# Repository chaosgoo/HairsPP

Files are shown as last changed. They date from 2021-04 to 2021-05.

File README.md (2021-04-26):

# HairsPP

语言: 中文, [English](README.En.md)




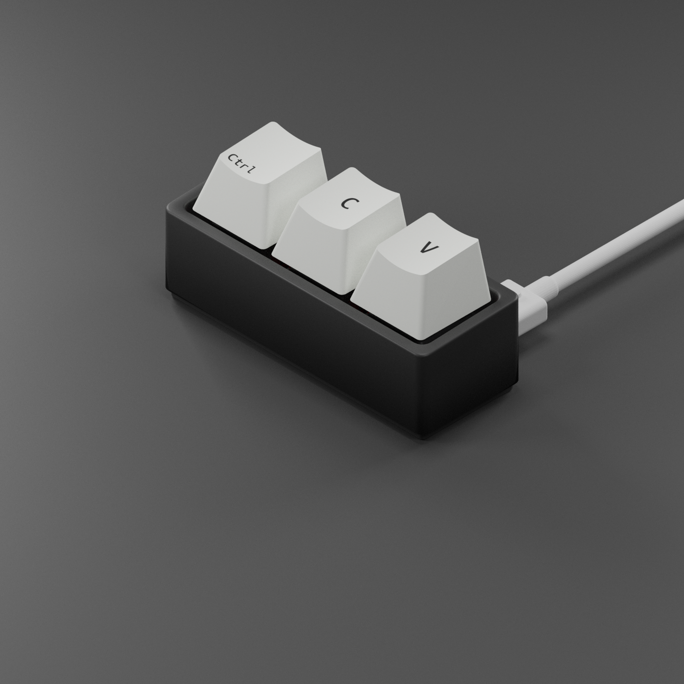
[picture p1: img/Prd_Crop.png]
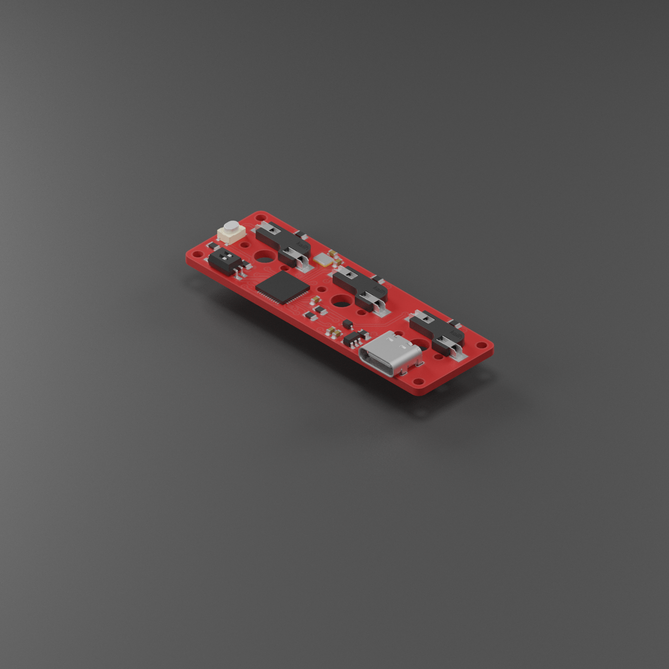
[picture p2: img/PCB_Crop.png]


[HairsPP](https://github.com/chaosgoo/HairsPP) 是Hairs Plus Plus的简写。[HairsPP](https://github.com/chaosgoo/HairsPP)是一个三键的机械键盘。
* 支持热插拔
* 支持连发模式
* 易学的源码
* 自定义按键映射

## TODO
* ~~20210412:电路~~ 
* ~~20210418:初版源码~~ 
* 壳体 
* PC端配置软件

## 食用指南
开关状态(左5号右6号) | 模式名称 | 描述 
:-:|:-:|:-:
00 | 配置模式 | 串口发送三个字符会自动分配到三个键上，一切正常串口会收到"ok"字符。
10 | 连发模式 | 按住按钮会不断触发点击事件
01 | 复位模式 | 恢复默认键位，通电前配置才有效
11 | 常规模式 | 普通键盘的普通行为

## 材料清单

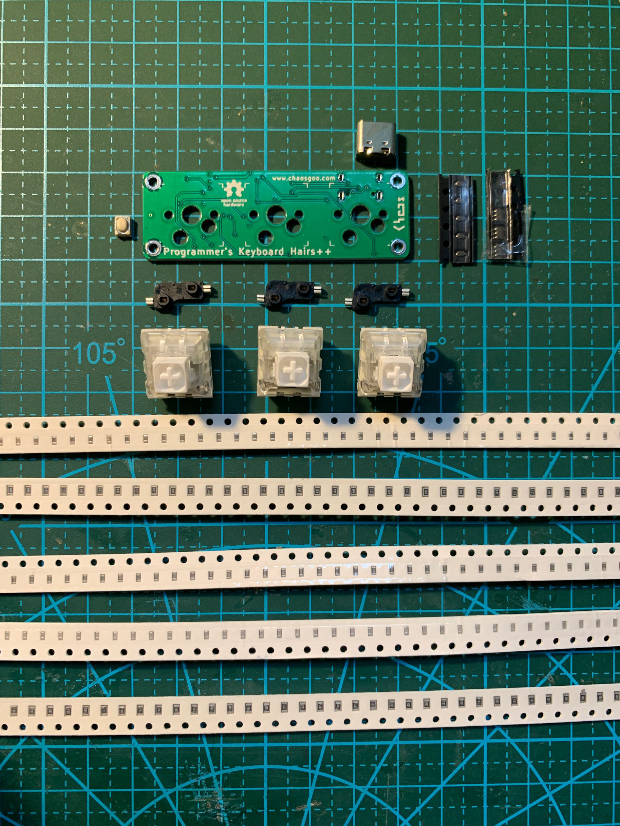
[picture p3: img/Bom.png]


序号 | 名称 | 数量 | 备注
-|-|-|-
1|ATMega32u4 | 1 | 主控芯片 QFN44封装
2|AP2112K-3.3 | 1 | 5V转3.3V芯片 SOT-23-5
3|16Mhz晶振 | 1 | 2.0*1.6
4|1uF电容 | 1 | 0603
5|22pf电容 | 2 | 0603
6|10uf电容 | 2 | 0603
7|1KΩ电阻 | 5 | 0805
8|10KΩ电阻 | 1 | 0805
9|22Ω电阻 | 2 | 0805
10|凯华热插拔轴座 | 3 | 1511系列
11|轴体 | 3 | 任意轴体
12|2位拨码开关 | 1 | 1.27mm
13|Type-C接口 | 1 | 16p
14|肖特基二极管 | 1 | BAT60JFILM SOD-323
15|微动开关 | 1 | 3x4x2.5 四脚贴片

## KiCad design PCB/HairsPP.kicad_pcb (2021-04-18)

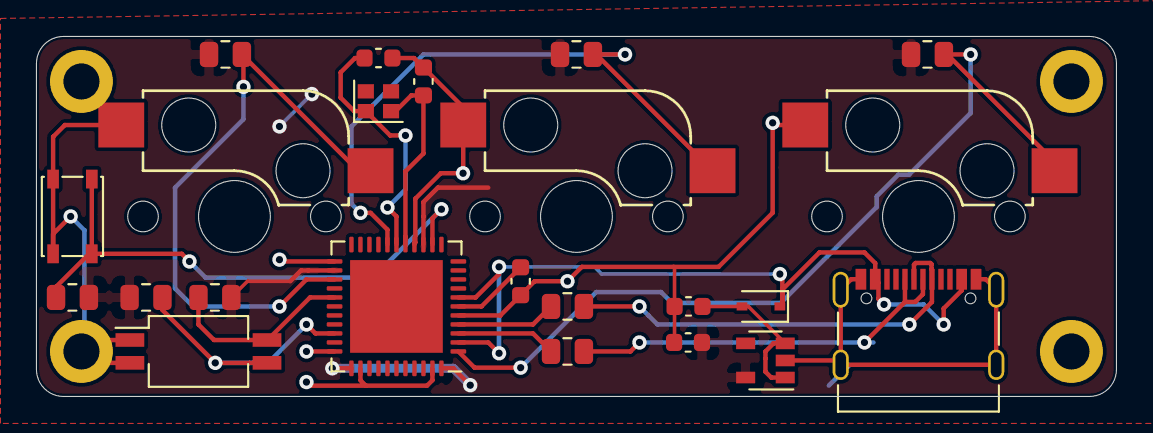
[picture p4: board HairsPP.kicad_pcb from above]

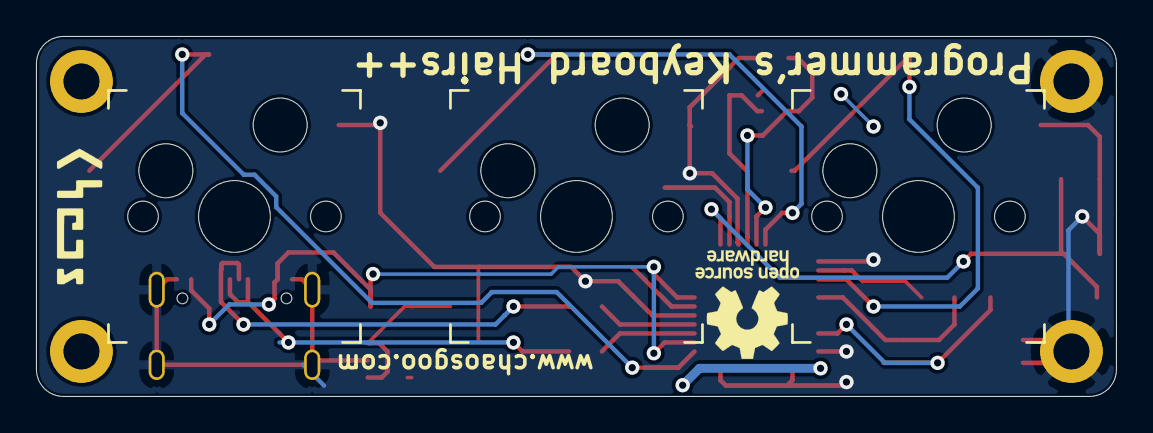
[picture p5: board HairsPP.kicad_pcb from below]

Board: 2 copper layers, 60.0 x 20.0 mm, 27 parts (3 on the bottom side), 17 nets.

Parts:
16MHz1: Crystal; Crystal_SMD_2016-4Pin_2.0x1.6mm
C1: 1uF; C_0603_1608Metric
C2, C4: 22pF; C_0603_1608Metric
C13: 10; C_0603_1608Metric
C19: 10uF; C_0603_1608Metric
D2: SD36_SOD323; D_SOD-323
J1: USB_C_Receptacle_USB2.0; USB_C_Receptacle_Palconn_UTC16-G
J2, J3, J4, J5: Conn_01x01; ScrewM2_SMT
MCU1: ATmega32U4-AU; QFN-44-1EP_7x7mm_P0.5mm_EP5.15x5.15mm
R1, R3, R4, R6, R8: 1K; R_0805_2012Metric
R2: 10K; R_0805_2012Metric
R5, R7: 22; R_0805_2012Metric
SW1, SW2, SW3: SW_Push; Kailh_socket_MX
SW4: SW_Push; SW_SPST_PTS810
SW5: SW_DIP_x02; SW_DIP_SPSTx02_Slide_Copal_CHS-02B_W7.62mm_P1.27mm
U1: AP2112K-3.3; SOT-23-5

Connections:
D4: MCU1.25, R1.2, SW1.2
D5: MCU1.31, R6.2, SW5.3
D6: MCU1.27, R8.2, SW5.4
D7: MCU1.1, R3.2, SW2.2
D+: MCU1.4, R7.1
D-: MCU1.3, R5.1
GND: C1.2, C2.2, C4.2, C13.2, C19.2, J1.A1, J1.A12, J1.B1, J1.B12, J1.S1, J4.1, J5.1, MCU1.5, MCU1.15, MCU1.23, MCU1.33, MCU1.35, MCU1.43, SW1.1, SW2.1, SW3.1, SW4.1, SW5.1, SW5.2, U1.2
unnamed: 16MHz1.1, C2.1, MCU1.17
unnamed: 16MHz1.2, C4.1, MCU1.16
unnamed: C19.1, D2.2, U1.1, U1.3
unnamed: J1.A6, J1.B6, R7.2
unnamed: J1.A7, J1.B7, R5.2
unnamed: MCU1.13, R2.2, SW4.2
SCL|D3: MCU1.18, R4.2, SW3.2
UCAP: C1.1, MCU1.6
VCC: C13.1, MCU1.14, MCU1.24, MCU1.34, MCU1.44, R1.1, R2.1, R3.1, R4.1, R6.1, R8.1, U1.5
V_USB: D2.1, J1.A4, J1.A9, J1.B4, J1.B9, MCU1.2, MCU1.7

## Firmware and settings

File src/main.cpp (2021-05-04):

/*
  main.cpp - HairsPP
  Original Copyright (c) 2021 Chaos Goo.  All right reserved.
  New version by Christopher Andrews 2015.

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
  You should have received a copy of the GNU Lesser General Public
  License along with this library; if not, write to the Free Software
  Foundation, Inc., 51 Franklin St, Fifth Floor, Boston, MA  02110-1301  USA
*/
#include <EEPROM.h>

#include "Keyboard.h"
#include "utils.h"

// 连发间隔 默认10ms
#define TRIGGER_INTERVAL 10

// 拨码开关的引脚5和6
#define SW_1_PIN 6
#define SW_2_PIN 5

extern const uint8_t _asciimap[128] PROGMEM;

// 按键数量
const int keyNum = 3;
// 按键对应引脚
const int keyPin[] = {4, 3, 7};
// 监听器
bool observer[keyNum];
// 具体的按键对应值，请参考"Keyboard.h"内宏定义
byte keyCodes[3] = {KEY_LEFT_CTRL, 'c', 'v'};
// 串口数据缓存
byte preferenceBuffer[10];
// 普通键盘模式
void keyboardMode() {
  if (!digitalRead(SW_1_PIN) && digitalRead(SW_2_PIN)) {
    // 连发模式
    for (int i = 0; i < keyNum; i++) {
      if (digitalRead(keyPin[i]) == LOW) {
        Keyboard.press(keyCodes[i]);
        Keyboard.release(keyCodes[i]);
      }
    }
    delay(TRIGGER_INTERVAL);
  } else {
    // 常规模式
    for (int i = 0; i < keyNum; i++) {
      if (digitalRead(keyPin[i]) == LOW) {
        if (observer[i]) {
          Keyboard.press(keyCodes[i]);
          observer[i] = false;
        }
      } else {
        Keyboard.release(keyCodes[i]);
        observer[i] = true;
      }
    }
  }
}

// 载入预设
void loadPreset() {
  keyCodes[0] = KEY_LEFT_CTRL;
  keyCodes[1] = 'c';
  keyCodes[2] = 'v';
}

// 保存配置
void savePreference() {
  for (int i = 0; i < keyNum; i++) {
    EEPROM.write(i, keyCodes[i]);
    // Serial.print((int)keyCodes[i]);
    // Serial.print(",");
  }
  EEPROM.write(0xF, 16);
}

// 载入配置
void loadPreference() {
  for (int i = 0; i < keyNum; i++) {
    keyCodes[i] = EEPROM.read(i);
  }
}

// 复位
void reset() {
  loadPreset();
  savePreference();
  EEPROM.write(0xF, 1);
}

void setup() {
  // 初始化键盘
  Keyboard.begin();
  // 初始化引脚
  for (int i = 0; i < keyNum; i++) {
    pinMode(keyPin[i], INPUT_PULLUP);
  }
  // 预设配置
  int defFlag = EEPROM.read(0xF);
  if (defFlag != 16) {
    reset();
  }
  loadPreference();
  Serial.begin(9600);
  // 仅仅在启动时候复位
  if (digitalRead(SW_1_PIN) && !digitalRead(SW_2_PIN)) {
    reset();
  }
}

void loop() {
  if (!digitalRead(SW_1_PIN) && !digitalRead(SW_2_PIN)) {
    while (Serial.available() > 0) {
      Serial.readBytes(preferenceBuffer, 4);
      if (checkSum((const char *)preferenceBuffer, 3) == preferenceBuffer[3]) {
        keyCodes[0] = preferenceBuffer[0];
        keyCodes[1] = preferenceBuffer[1];
        keyCodes[2] = preferenceBuffer[2];
        // keyCodes[0] = (byte)_asciimap + (preferenceBuffer[0] & 0xff);
        // keyCodes[1] = (byte)_asciimap + (preferenceBuffer[1] & 0xff);
        // keyCodes[2] = (byte)_asciimap + (preferenceBuffer[2] & 0xff);
        savePreference();
        loadPreference();
        Serial.print("ok");
      } else {
        Serial.print("err");
      }
    }
  } else {
    keyboardMode();
  }
}

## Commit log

2021-04-18 Add introduction
    [HairsPP-B_Cu.gbr, HairsPP-B_Mask.gbr, HairsPP-B_Paste.gbr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]
2021-04-18 添加按键映射功能
2021-04-26 1.更新材料清单
2021-05-04 增加串口修改键位功能

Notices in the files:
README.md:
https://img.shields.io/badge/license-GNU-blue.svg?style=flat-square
